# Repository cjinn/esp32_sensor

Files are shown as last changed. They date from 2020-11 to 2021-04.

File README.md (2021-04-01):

# ESP32 Sensor Module
This repository outlines an attempt to make a universal ESP32 board to conduct IoT projects with the help of sensors. As such, it is highly customisable and will most likely undergo many revisions.

The goal is to have multiple of these ESP32 sensor modules interact with each other using mesh Wi-Fi to share information with each other.

# Table of Contents
- [ESP32 Sensor Module](#esp32-sensor-module)
- [Table of Contents](#table-of-contents)
- [Hardware Versions](#hardware-versions)
  - [v0.0.3b](#v003b)
    - [v0.0.3c](#v003c)
    - [Known Hardware Issues](#known-hardware-issues)
- [Acknowledgements](#acknowledgements)

# Hardware Versions
Each hardware revision will be updated and the version as such. This version system is adopted from v0.0.4 onwards. The convection is as follows:

X.Y.ZA
- X: Major version number of the design. It is assumed there are major changes to the overall design including PCB, components, fucntionality, purpose, etc.
- Y: Minor version number of the design. Any increment on this signifies a minor design revision. Most likely an electrical characteristic change and/or component replacement.
- Z: Revision version number of the design. Any increment on this signifies a commit has been made to the design. Most likely adjustments to facilitate assembly houses, manufacturing and production.
- A: Alphabetical designation. Used to indicate even more minor adjustments like spelling mistakes and refreshing files.

## v0.0.3b
Originally a 4-layer PCB, it was redesigned to a 2-layer PCB in order to meet capstone project deadlines and it is the first iteration that was manufactured, tested and worked (well, most of it anyways). As such, it is noticebly bare-bones and has hardware design flaws. It is not recommended to go with this.

### v0.0.3c
Refreshed gerber files, schematics and BOM to be packaged such that it can be used to shop around between assembly houses. No meaningful changes since v0.0.3b.

### Known Hardware Issues
- [IMU SDA pin interferes with ESP32 boot up](https://github.com/cjinn/esp32_sensor/issues/2)
- [Crystal Oscillator missing from Hardware Design](https://github.com/cjinn/esp32_sensor/issues/1)

# Acknowledgements
Thanks to Isaac Tan for helping me design, test and realise this project from the very beginning.

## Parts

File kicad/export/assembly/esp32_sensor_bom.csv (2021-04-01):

Component | Description | Part | References | Value | Footprint | Quantity Per PCB | Datasheet | Vendor | Vendor Part Name | Part Name | Manufacturer | PROD_ID | digikeypn | PARTREV | STANDARD
1 |  | C-Device | C_ESP_1 C_PW_4 | 0.1uF | CAPC1608X90 | 2 | https://www.yageo.com/upload/media/product/productsearch/datasheet/mlcc/UPY-GPHC_X7R_6.3V-to-50V_18.pdf | DigiKey Canada | 311-1777-1-ND | CC0603JRX7R8BB104 | Yageo
2 |  | C_Small-Device | C_IMU_1 C_IMU_2 C_IMU_3 | 100nF | CAPC1608X90N | 3 | https://product.tdk.com/info/en/catalog/datasheets/mlcc_commercial_midvoltage_en.pdf | DigiKey Canada | 445-1304-1-ND | C1608X7R2A103K080AA | TDK Corporation
3 |  | C-Device | C_PW_1 C_PW_3 | 1uF | 603 | 2 | https://content.kemet.com/datasheets/KEM_C1002_X7R_SMD.pdf | DigiKey Canada | 399-7847-1-ND | C0603C105K4RACTU | Kermet
4 |  | C_Small-Device | C_PW_2 C_PW_5 | 4.7uF | C1206C475K3RACAUTO | 2 | https://api.kemet.com/component-edge/download/specsheet/C1206C475K3RACAUTO.pdf | DigiKey Canada | 399-7029-1-ND | C1206C475K3RACAUTO | Kermet
5 |  | CP-Device | CP_ESP_1 | 100uF | UCB0J101MCL1GS | 1 | https://www.nichicon.co.jp/english/products/pdfs/e-ucb.pdf | DigiKey Canada | 493-9357-1-ND | UCB0J101MCL1GS | Nichicon
6 |  | BAT20JFILM | D_PW_1 D_PW_2 D_PW_3 | BAT20JFILM | BAT20JFILM | 3 | https://www.st.com/content/ccc/resource/technical/document/datasheet/group1/81/a4/1f/0e/ca/8c/47/ba/CD00012201/files/CD00012201.pdf/jcr:content/translations/e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 | DigiKey Canada | 497-3381-1-ND | BAT20JFILM | STMicroelectronics | DIO-11623
7 |  | 4157 | J_1 J_2 | 4157 | PinSocket_1x20_P2.54mm_Vertical | 2 |  | DigiKey Canada |  |  | Adafruit Industries LLC |  | 1528-2929-ND
8 |  | Header_Pin_1 | J_CN_3 J_CN_4 J_PW_3 | Header_Pin_1 | PinHeader_1x01_P2.54mm_Vertical | 3
9 |  | Header_Pin_2 | J_PW_1 J_PW_2 | Header_Pin_2 | PinHeader_1x02_P2.54mm_Vertical | 2
10 |  | Header_Pin_4 | J_CN_1 J_CN_2 | Header_Pin_4 | PinHeader_1x04_P2.54mm_Vertical | 2
11 |  | Header_Pin_2 | J_5 | IMU_INT1 | PinHeader_1x02_P2.54mm_Vertical | 1
12 |  | Header_Pin_2 | J_4 | IMU_INT2 | PinHeader_1x02_P2.54mm_Vertical | 1
13 |  | Header_Pin_2 | J_6 | IMU_SCL | PinHeader_1x02_P2.54mm_Vertical | 1
14 |  | Header_Pin_2 | J_7 | IMU_SDA | PinHeader_1x02_P2.54mm_Vertical | 1
15 |  | Header_Pin_8 | J_3 | SPI | PinHeader_1x08_P2.54mm_Vertical | 1
16 |  | L-Device | L_PW_1 | 4.7uH | CV201210-4R7K | 1 | https://www.bourns.com/docs/Product-Datasheets/CV201210.pdf | DigiKey Canada | CV201210-4R7KCT-ND | CV201210-4R7K | Bourns Inc.
17 |  | LED-Device | LED_ESP_1 | LED | LED_0603_1608Metric | 1 | https://katalog.we-online.de/led/datasheet/150060YS75000.pdf | DigiKey Canada | 732-4981-1-ND | 150060YS75000 | Würth Elektronik
18 |  | IRLML5103TRPBF | Q_PW_1 | IRLML5103TRPBF | IRLML5103TRPBF | 1 | https://www.infineon.com/dgdl/irlml5103pbf.pdf?fileId=5546d462533600a401535668505d2617 | DigiKey Canada | IRLML5103PBFCT-ND | IRLML5103TRPBF | Infineon Technologies
19 |  | R_Small-Device | R_ESP_1 R_ESP_3 R_ESP_5 | 500 | RESC1508X55N | 3 | https://www.vishay.com/docs/28916/mcxhp.pdf | DigiKey Canada | 749-1523-1-ND | MCT0603PD4990DP500 | Vishay
20 |  | R_Small-Device | R_IMU_1 R_IMU_2 | 4.7k | RESC1608X55N | 2 | https://www.yageo.com/upload/media/product/productsearch/datasheet/rchip/PYu-RT_1-to-0.01_RoHS_L_12.pdf | DigiKey Canada | 311-4.7KDCT-ND | RT0603DRD074K7L | Yageo
21 |  | R_Small-Device | R_ESP_2 R_ESP_4 R_PW_1 | 10k | RESC1608X55N | 3 | https://www.yageo.com/upload/media/product/productsearch/datasheet/rchip/PYu-RT_1-to-0.01_RoHS_L_12.pdf | DigiKey Canada | YAG2321CT-ND | RT0603FRE0710KL | Yageo
22 |  | R_Small-Device | R_PW_2 R_PW_3 | 100k | RESC1608X55N | 2 | https://www.yageo.com/upload/media/product/productsearch/datasheet/rchip/PYu-RT_1-to-0.01_RoHS_L_12.pdf | DigiKey Canada | 311-2395-1-ND | RT0603DRE07100KL | Yageo
23 |  | R_Small-Device | R_PW_4 | 115k | RESC1608X55N | 1 | https://www.yageo.com/upload/media/product/productsearch/datasheet/rchip/PYu-RT_1-to-0.01_RoHS_L_12.pdf | DigiKey Canada | 311-2218-1-ND | RT0402DRE07115KL | Yageo
24 |  | PTS647SK38SMTR2LFS | SW_ESP_1 SW_ESP_2 | PTS647SK38SMTR2LFS | PTS647SK38SMTR2LFS | 2 | https://www.ckswitches.com/media/2567/pts647.pdf | DigiKey Canada | PTS647SK38SMTR2LFSCT-ND | PTS 647 SK38 SMTR2 LFS | C&K
25 |  | ESP32-WROOM-32D-RF_Module | U_ESP_1 | ESP32-WROOM-32D | ESP32-WROOM-32 | 1 | https://www.espressif.com/sites/default/files/documentation/esp32-wroom-32d_esp32-wroom-32u_datasheet_en.pdf | DigiKey Canada | 1965-ESP32-WROOM-32D(4MB)CT-ND | USB4110-GF-A | Espressif Systems
26 |  | LSM6DSMTR | U_IMU_1 | LSM6DSMTR | LSM6DSMTR | 1 | https://www.st.com/content/ccc/resource/technical/document/datasheet/76/27/cf/88/c5/03/42/6b/DM00218116.pdf/files/DM00218116.pdf/jcr:content/translations/en.D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 | DigiKey Canada | 497-16696-1-ND | LSM6DSMTR | STMicroelectronics
27 |  | MAX25276ATCA_VY+ | U_PW_1 | MAX25276ATCA_VY+ | MAX25276ATCAVY | 1 | https://datasheets.maximintegrated.com/en/ds/MAX20075-MAX25276.pdf | DigiKey Canada | 175-MAX25276ATCA/VY+-ND | MAX25276ATCA_VY+ | Maxim Integrated
28 |  | USB4110-GF-A | U_CN_1 | USB4110-GF-A | USB4110-GF-A | 1 | https://gct.co/files/drawings/usb4110.pdf | DigiKey Canada | 2073-USB4110-GF-A-1-ND | PTS647SK38SMTR2LFS | GCT |  |  | A | Manufacturer Recommendations
Component Groups: | 28
Component Count: | 47
Fitted Components: | 47
Number of PCBs: | 1
Total components: | 47
Schematic Version: | v0.0.3
Schematic Date: | 31/3/2021
PCB Variant: | udefault
BoM Date: | 03/31/21 16:14:19
Schematic Source: | esp32_sensor.sch
KiCad Version: | Eeschema (5.1.9)-1

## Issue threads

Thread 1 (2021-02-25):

Crystal Oscillator missing from Hardware Design

cjinn, 2021-02-25:
## Summary
As noted in the[ Hardware Design Guidelines](https://www.espressif.com/sites/default/files/documentation/esp32_hardware_design_guidelines_en.pdf) on page 6 for the External Clock Source, the ESP32 requires a 40 MHz crystal oscillator in order to run Wi-Fi/Bluetooth firmware. This is an oversight on the hardware design, causing any firmware for Wi-Fi/Bluetooth to fail for v0.0.3b.

## Proposed Solution
In the next hardware iteration, include a crystal oscillator into the design.

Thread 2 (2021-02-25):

IMU SDA pin interferes with ESP32 boot up

cjinn, 2021-02-25:
## Summary
In the current hardware design, the ESP32 will not boot up properly if it is connected to the IMU on start-up, specifically the IMU SDA pin with GPIO12 (MTDI) or Pin14 for the ESP32. The [ESP32 Boot Mode ](https://github.com/espressif/esptool/wiki/ESP32-Boot-Mode-Selection), when driven high, will have a flash voltage of 1.8V which interferes with the 3.3V SPI Flash as outlined in the [ESP32 datasheet](https://www.espressif.com/sites/default/files/documentation/esp32-wroom-32d_esp32-wroom-32u_datasheet_en.pdf).

The current workaround is to not connect the IMU to the ESP32 till after power up.

## Proposed Solution
Revise GPIO layout of the ESP32 to connect to IMU.

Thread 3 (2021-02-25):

IMU Self-Reset with FTDI

cjinn, 2021-02-25:
The ESP32 should interface with the FTDI hardware pins such that it can auto-reset itself accordingly when being programmed.

See [this thread](https://forum.micropython.org/viewtopic.php?f=18&t=4966) for an example.

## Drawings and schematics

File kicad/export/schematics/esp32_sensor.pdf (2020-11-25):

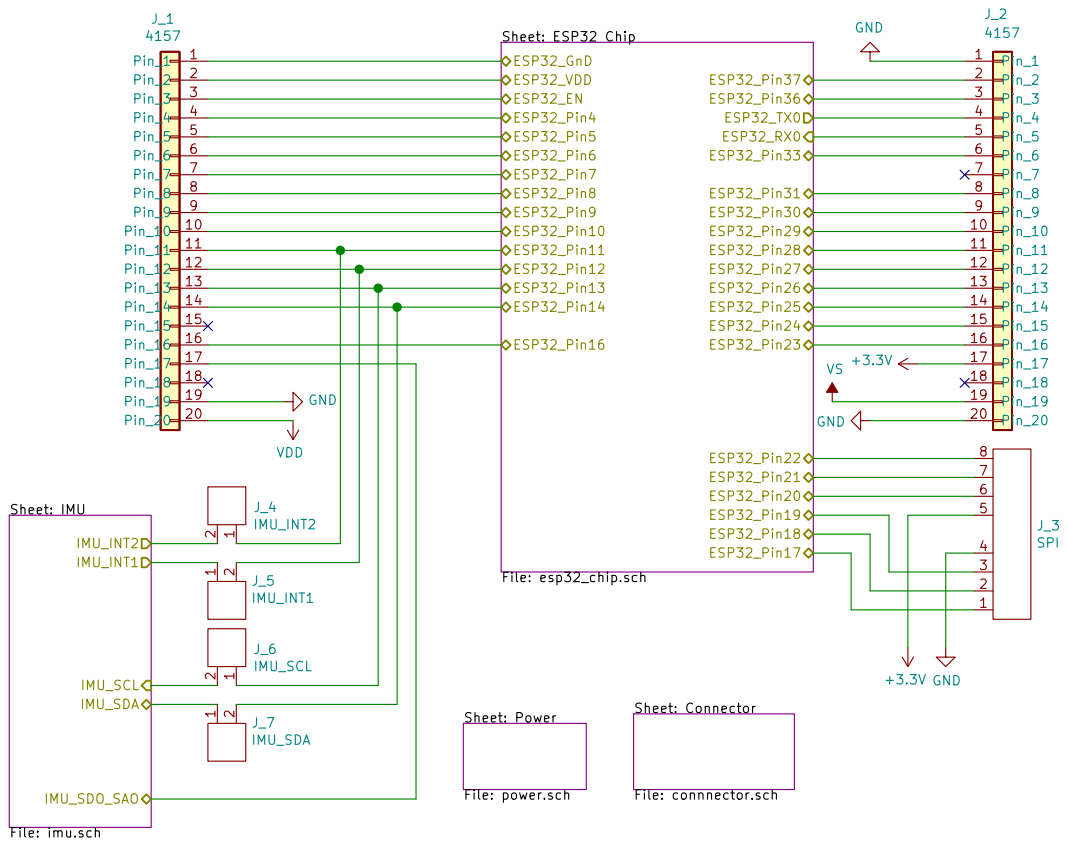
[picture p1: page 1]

Component Identifier: Sheet: IMU

Sheet: Connector File: connnector.sch

File: esp32_sensor.sch Sheet: / Created by Choong Jin Ng | jin3838@gmail.com

Id: 1/5 Title: ESP32 Sensor Module

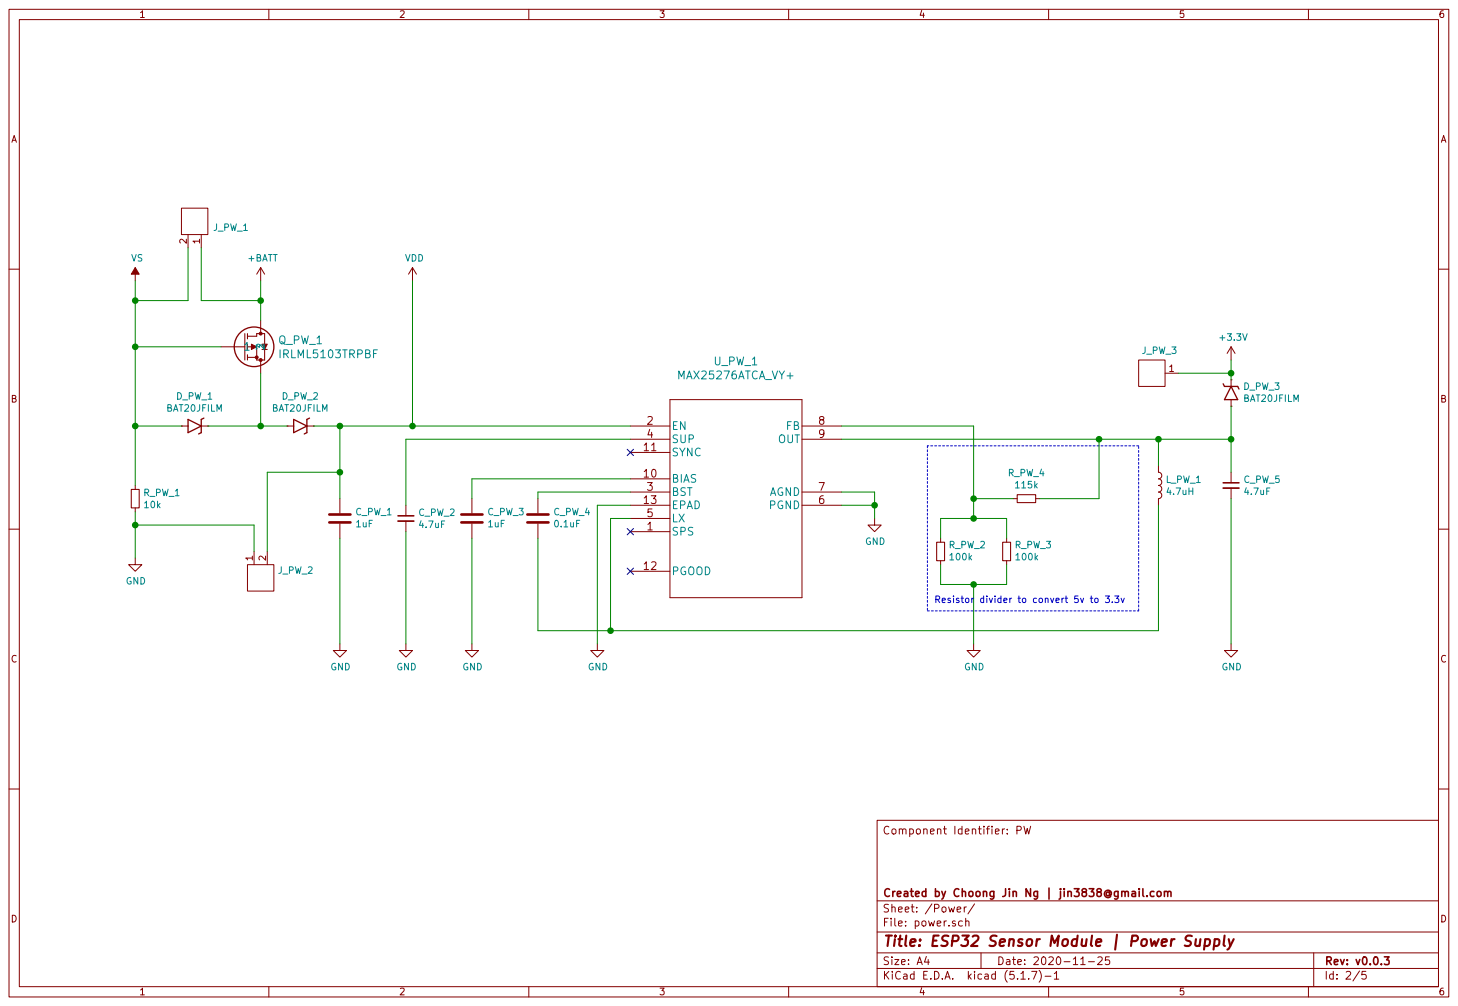
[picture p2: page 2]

File: power.sch Sheet: /Power/ Created by Choong Jin Ng | jin3838@gmail.com

Id: 2/5 Title: ESP32 Sensor Module | Power Supply

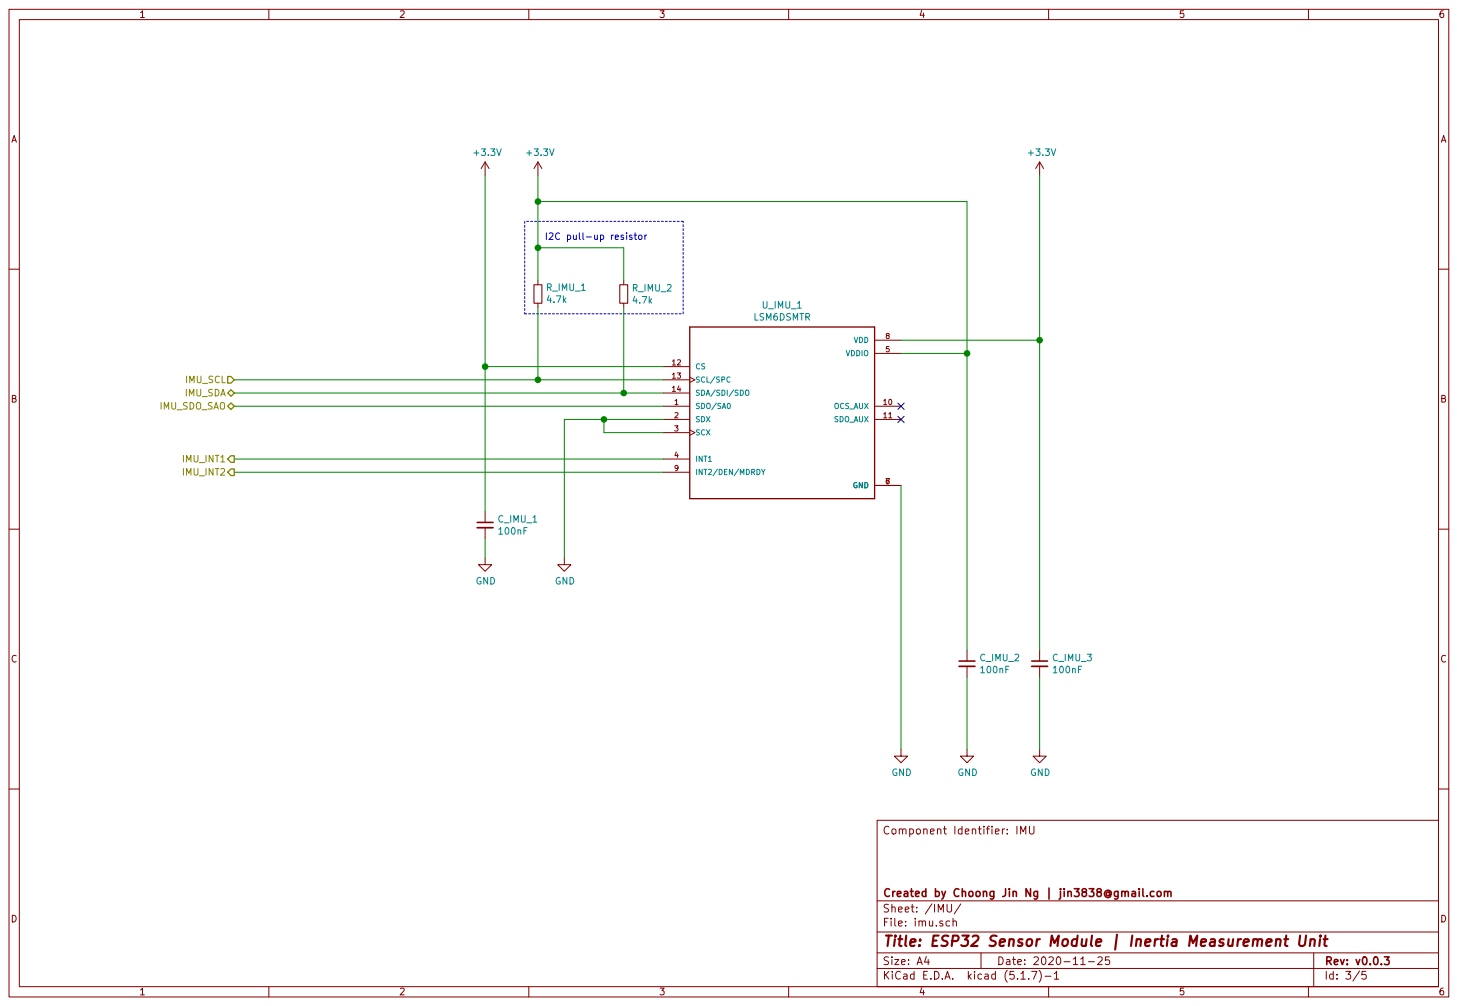
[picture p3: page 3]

Id: 3/5 Title: ESP32 Sensor Module | Inertia Measurement Unit File: imu.sch Sheet: /IMU/ Created by Choong Jin Ng | jin3838@gmail.com

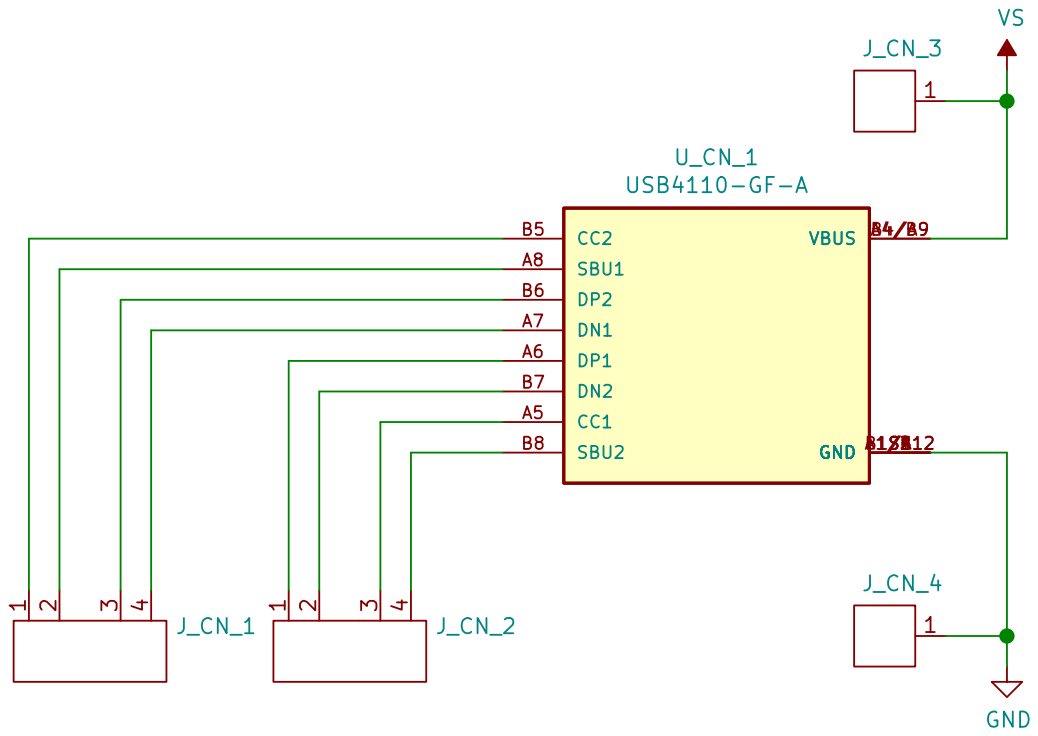
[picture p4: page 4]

Id: 4/5 Title: ESP32 Sensor Module | Connector File: connnector.sch Sheet: /Connector/ Created by Choong Jin Ng | jin3838@gmail.com

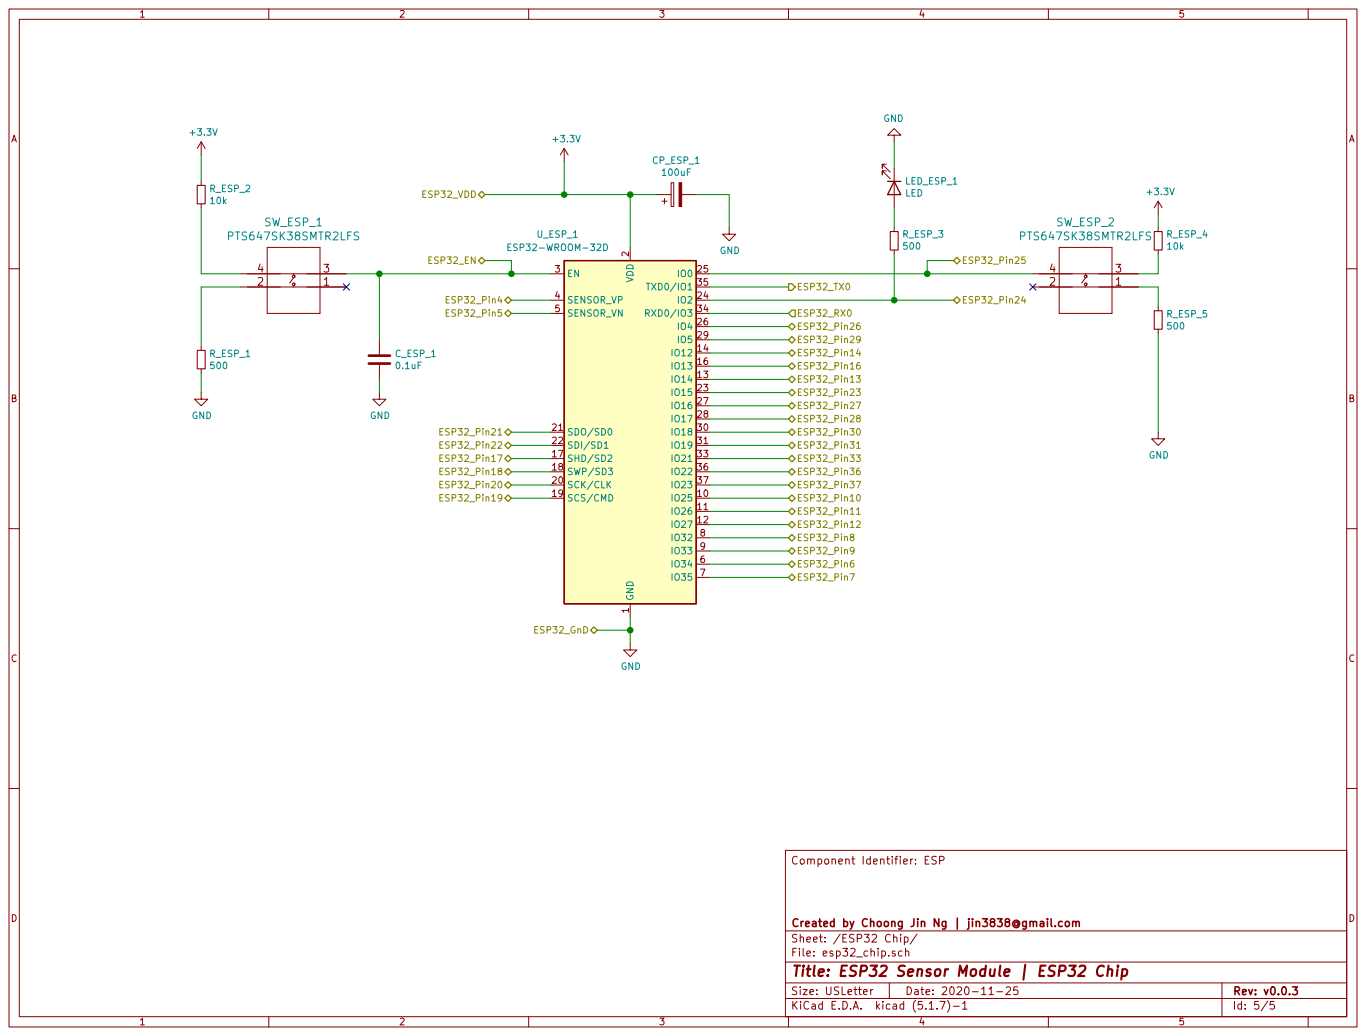
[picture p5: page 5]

2 SCK/CLK 20 SDO/SD0 21 SDI/SD1 22

Created by Choong Jin Ng | jin3838@gmail.com
Sheet: /ESP32 Chip/
File: esp32_chip.sch
Id: 5/5 Title: ESP32 Sensor Module | ESP32 Chip

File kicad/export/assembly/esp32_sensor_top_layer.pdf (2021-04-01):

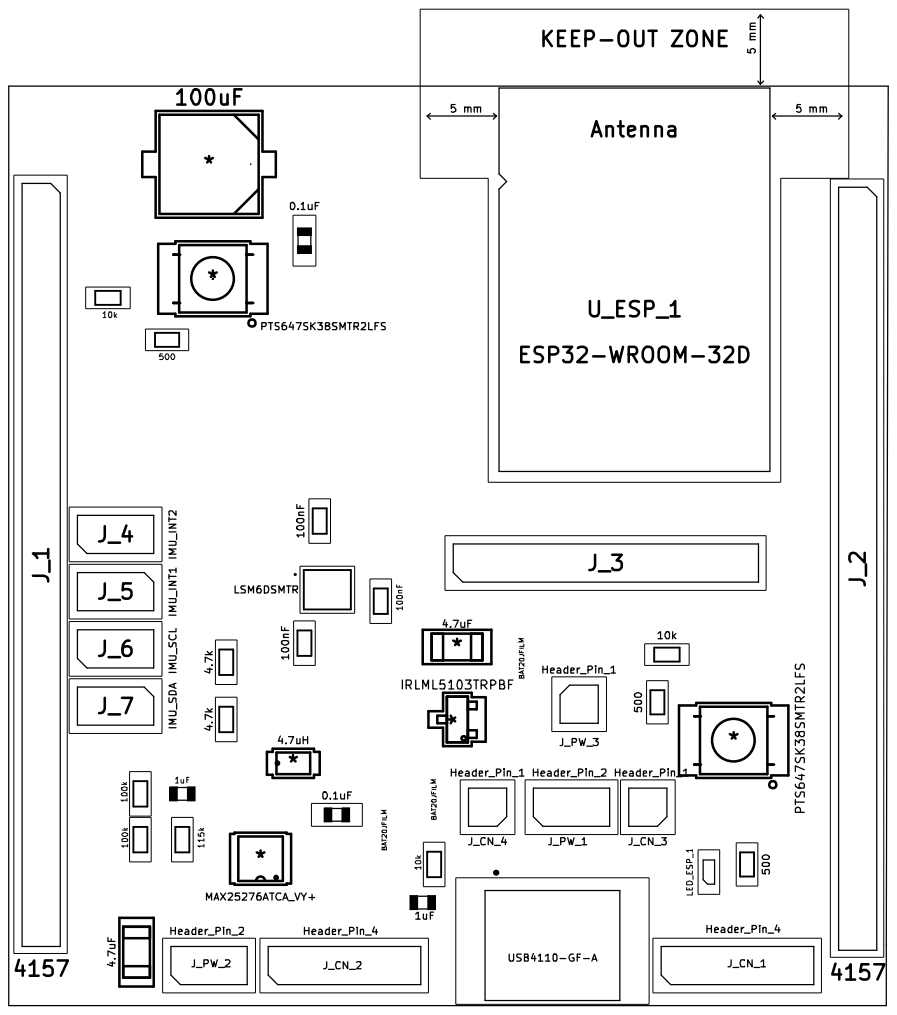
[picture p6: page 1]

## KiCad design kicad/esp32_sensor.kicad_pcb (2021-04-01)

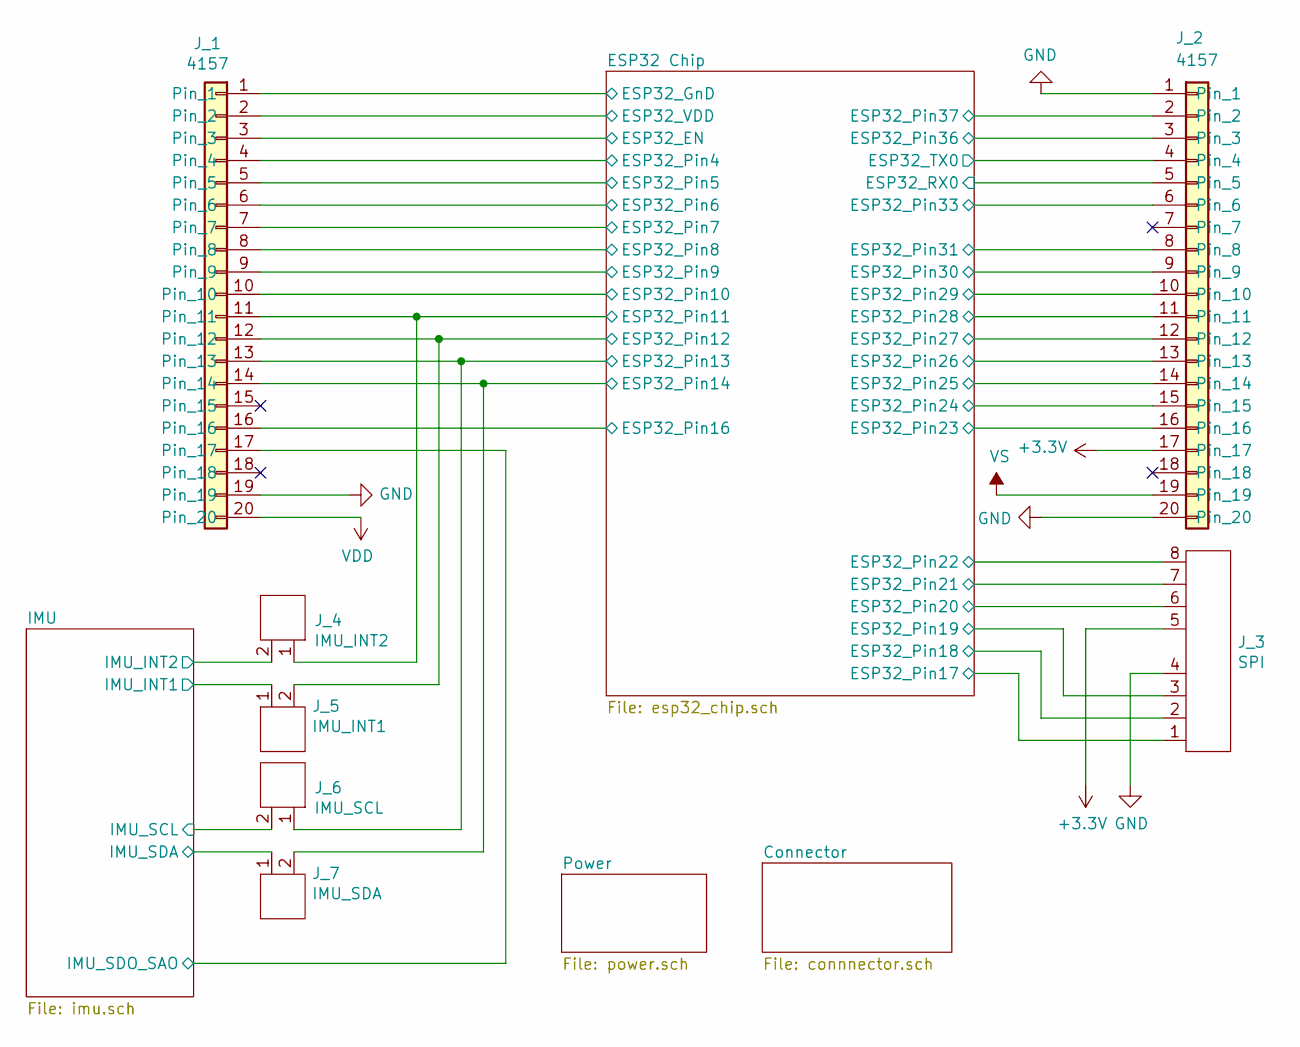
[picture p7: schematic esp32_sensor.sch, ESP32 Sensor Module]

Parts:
J_1, J_2: 4157; PinSocket_1x20_P2.54mm_Vertical; digikeypn 1528-2929-ND
J_3: SPI; PinHeader_1x08_P2.54mm_Vertical
J_4: IMU_INT2; PinHeader_1x02_P2.54mm_Vertical
J_5: IMU_INT1; PinHeader_1x02_P2.54mm_Vertical
J_6: IMU_SCL; PinHeader_1x02_P2.54mm_Vertical
J_7: IMU_SDA; PinHeader_1x02_P2.54mm_Vertical

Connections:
+3V3: J_1.2, J_2.17, J_3.5; also elsewhere on the board
/ESP32 Chip/ESP32_EN: J_1.3; also elsewhere on the board
/ESP32 Chip/ESP32_Pin4: J_1.4; also elsewhere on the board
/ESP32 Chip/ESP32_Pin5: J_1.5; also elsewhere on the board
/ESP32 Chip/ESP32_Pin6: J_1.6; also elsewhere on the board
/ESP32 Chip/ESP32_Pin7: J_1.7; also elsewhere on the board
/ESP32 Chip/ESP32_Pin8: J_1.8; also elsewhere on the board
/ESP32 Chip/ESP32_Pin9: J_1.9; also elsewhere on the board
/ESP32 Chip/ESP32_Pin10: J_1.10; also elsewhere on the board
/ESP32 Chip/ESP32_Pin11: J_1.11, J_4.1; also elsewhere on the board
/ESP32 Chip/ESP32_Pin12: J_1.12, J_5.2; also elsewhere on the board
/ESP32 Chip/ESP32_Pin13: J_1.13, J_6.1; also elsewhere on the board
/ESP32 Chip/ESP32_Pin14: J_1.14, J_7.2; also elsewhere on the board
/ESP32 Chip/ESP32_Pin16: J_1.16; also elsewhere on the board
/ESP32 Chip/ESP32_Pin17: J_3.1; also elsewhere on the board
/ESP32 Chip/ESP32_Pin18: J_3.2; also elsewhere on the board
/ESP32 Chip/ESP32_Pin19: J_3.3; also elsewhere on the board
/ESP32 Chip/ESP32_Pin20: J_3.6; also elsewhere on the board
/ESP32 Chip/ESP32_Pin21: J_3.7; also elsewhere on the board
/ESP32 Chip/ESP32_Pin22: J_3.8; also elsewhere on the board
/ESP32 Chip/ESP32_Pin23: J_2.16; also elsewhere on the board
/ESP32 Chip/ESP32_Pin24: J_2.15; also elsewhere on the board
/ESP32 Chip/ESP32_Pin25: J_2.14; also elsewhere on the board
/ESP32 Chip/ESP32_Pin26: J_2.13; also elsewhere on the board
/ESP32 Chip/ESP32_Pin27: J_2.12; also elsewhere on the board
/ESP32 Chip/ESP32_Pin28: J_2.11; also elsewhere on the board
/ESP32 Chip/ESP32_Pin29: J_2.10; also elsewhere on the board
/ESP32 Chip/ESP32_Pin30: J_2.9; also elsewhere on the board
/ESP32 Chip/ESP32_Pin31: J_2.8; also elsewhere on the board
/ESP32 Chip/ESP32_Pin33: J_2.6; also elsewhere on the board
/ESP32 Chip/ESP32_Pin36: J_2.3; also elsewhere on the board
/ESP32 Chip/ESP32_Pin37: J_2.2; also elsewhere on the board
/ESP32 Chip/ESP32_RX0: J_2.5; also elsewhere on the board
/ESP32 Chip/ESP32_TX0: J_2.4; also elsewhere on the board
/IMU/IMU_INT1: J_5.1; also elsewhere on the board
/IMU/IMU_INT2: J_4.2; also elsewhere on the board
/IMU/IMU_SCL: J_6.2; also elsewhere on the board
/IMU/IMU_SDA: J_7.1; also elsewhere on the board
/IMU/IMU_SDO_SAO: J_1.17; also elsewhere on the board
GND: J_1.1, J_1.19, J_2.1, J_2.20, J_3.4; also elsewhere on the board
VDD: J_1.20; also elsewhere on the board
VS: J_2.19; also elsewhere on the board

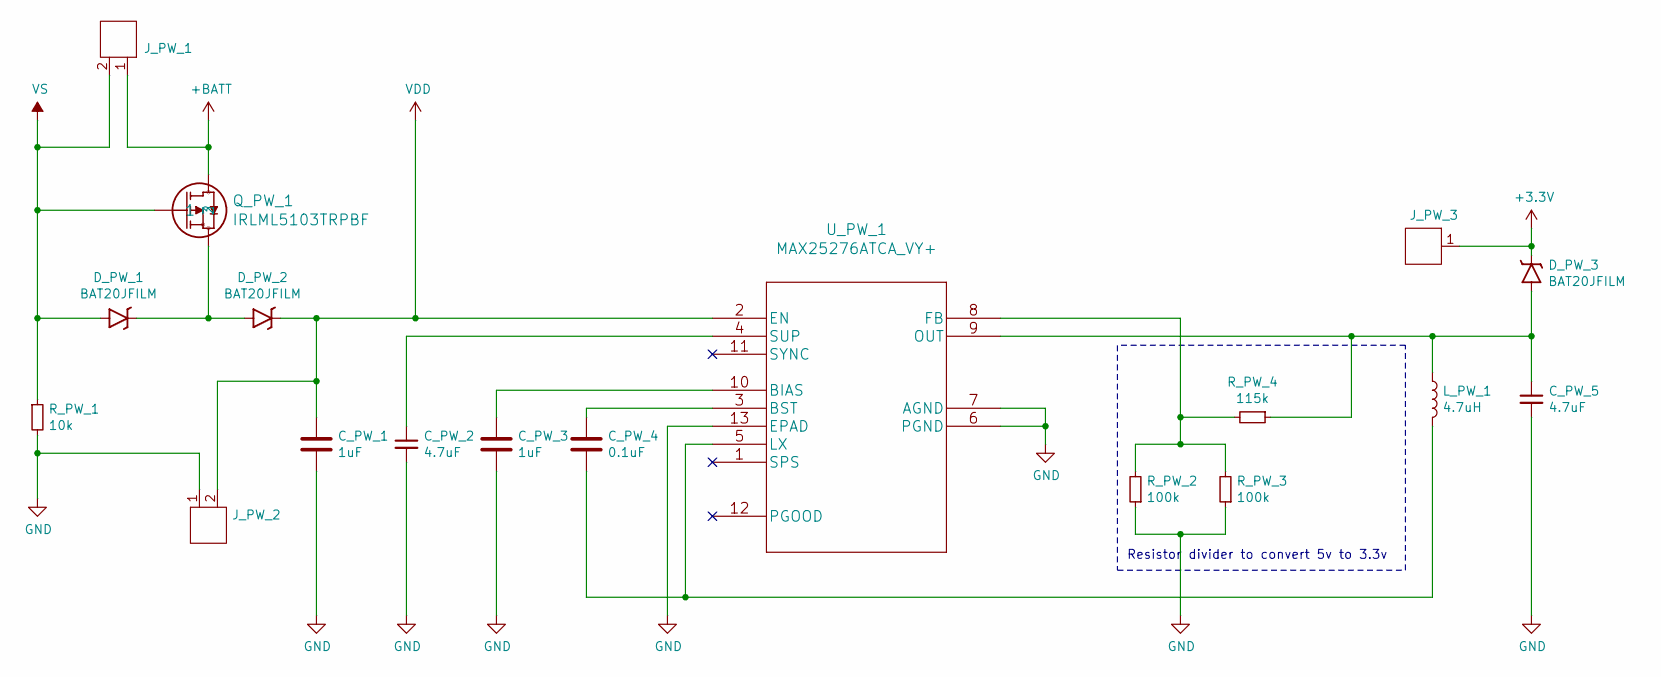
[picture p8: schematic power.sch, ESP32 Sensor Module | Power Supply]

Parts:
C_PW_1, C_PW_3: 1uF; 0603; Part Name C0603C105K4RACTU
C_PW_2, C_PW_5: 4.7uF; C1206C475K3RACAUTO; Part Name C1206C475K3RACAUTO
C_PW_4: 0.1uF; CAPC1608X90; Part Name CC0603JRX7R8BB104
D_PW_1, D_PW_2, D_PW_3: BAT20JFILM; Part Name BAT20JFILM
J_PW_1, J_PW_2: Header_Pin_2; PinHeader_1x02_P2.54mm_Vertical
J_PW_3: Header_Pin_1; PinHeader_1x01_P2.54mm_Vertical
L_PW_1: 4.7uH; CV201210-4R7K; Part Name CV201210-4R7K
Q_PW_1: IRLML5103TRPBF; Part Name IRLML5103TRPBF
R_PW_1: 10k; RESC1608X55N; Part Name RT0603FRE0710KL
R_PW_2, R_PW_3: 100k; RESC1608X55N; Part Name RT0603DRE07100KL
R_PW_4: 115k; RESC1608X55N; Part Name RT0402DRE07115KL
U_PW_1: MAX25276ATCA_VY+; MAX25276ATCAVY; Part Name MAX25276ATCA_VY+

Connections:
+3V3: D_PW_3.C, J_PW_3.1; also elsewhere on the board
+BATT: J_PW_1.1, Q_PW_1.2
GND: C_PW_1.1, C_PW_2.2, C_PW_3.1, C_PW_5.2, J_PW_2.1, R_PW_1.2, R_PW_2.1, R_PW_3.1, U_PW_1.6 (PGND), U_PW_1.7 (AGND), U_PW_1.13 (EPAD); also elsewhere on the board
unnamed: C_PW_2.1, U_PW_1.4 (SUP)
unnamed: C_PW_3.2, U_PW_1.10 (BIAS)
unnamed: C_PW_4.1, L_PW_1.2, U_PW_1.5 (LX)
unnamed: C_PW_4.2, U_PW_1.3 (BST)
unnamed: C_PW_5.1, D_PW_3.A, L_PW_1.1, R_PW_4.1, U_PW_1.9 (OUT)
unnamed: D_PW_1.C, D_PW_2.A, Q_PW_1.3
unnamed: R_PW_2.2, R_PW_3.2, R_PW_4.2, U_PW_1.8 (FB)
VDD: C_PW_1.2, D_PW_2.C, J_PW_2.2, U_PW_1.2 (EN); also elsewhere on the board
VS: D_PW_1.A, J_PW_1.2, Q_PW_1.1, R_PW_1.1; also elsewhere on the board

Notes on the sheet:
Resistor divider to convert 5v to 3.3v

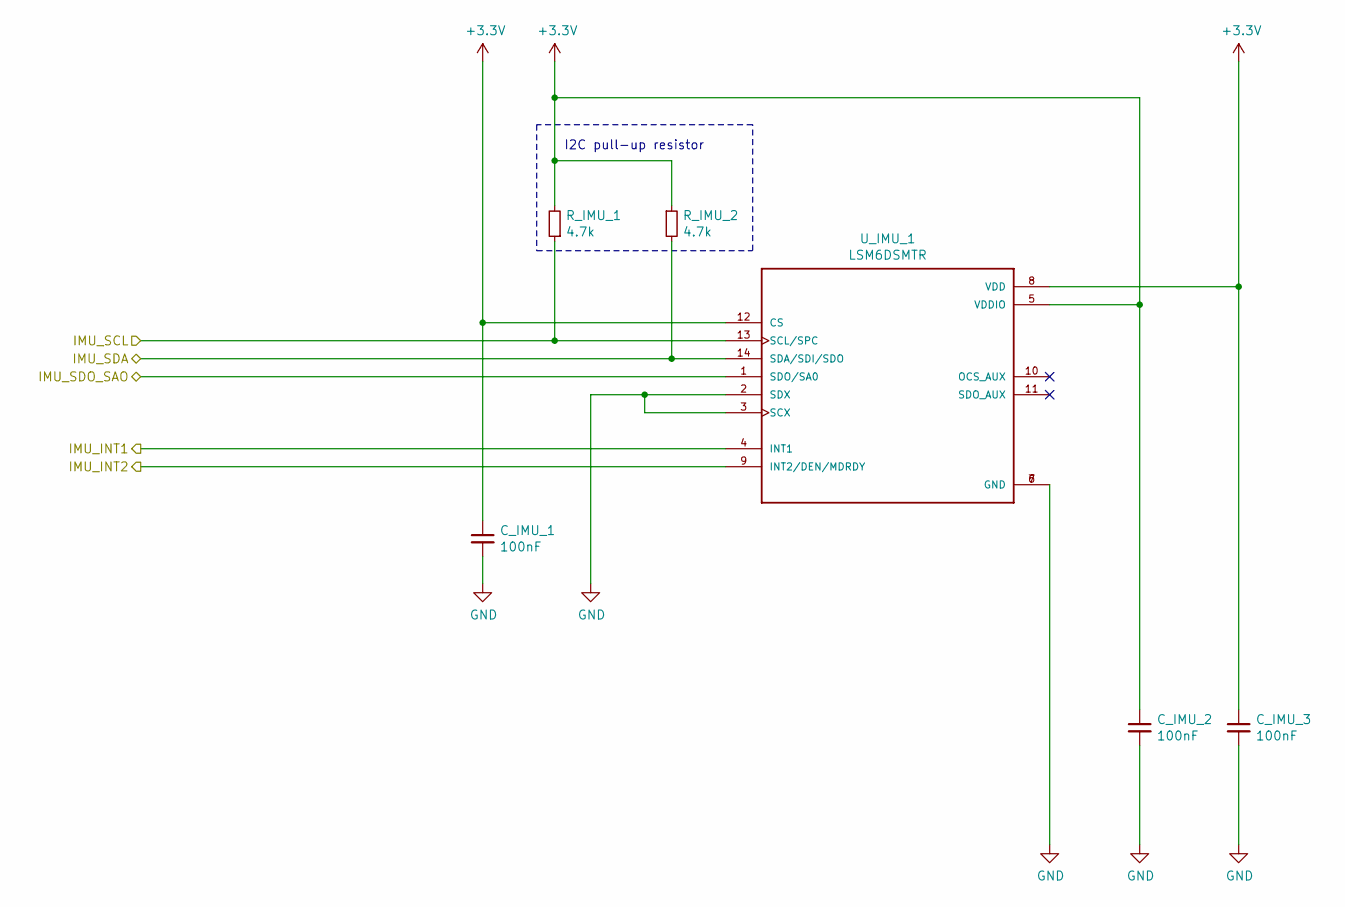
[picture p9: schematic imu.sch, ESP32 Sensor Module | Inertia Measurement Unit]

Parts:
C_IMU_1, C_IMU_2, C_IMU_3: 100nF; CAPC1608X90N; Part Name C1608X7R2A103K080AA
R_IMU_1, R_IMU_2: 4.7k; RESC1608X55N; Part Name RT0603DRD074K7L
U_IMU_1: LSM6DSMTR; Part Name LSM6DSMTR

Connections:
+3V3: C_IMU_1.1, C_IMU_2.1, C_IMU_3.1, R_IMU_1.2, R_IMU_2.1, U_IMU_1.5 (VDDIO), U_IMU_1.8 (VDD), U_IMU_1.12 (CS); also elsewhere on the board
/IMU/IMU_INT1: U_IMU_1.4 (INT1); also elsewhere on the board
/IMU/IMU_INT2: U_IMU_1.9 (INT2/DEN/MDRDY); also elsewhere on the board
/IMU/IMU_SCL: R_IMU_1.1, U_IMU_1.13 (SCL/SPC); also elsewhere on the board
/IMU/IMU_SDA: R_IMU_2.2, U_IMU_1.14 (SDA/SDI/SDO); also elsewhere on the board
/IMU/IMU_SDO_SAO: U_IMU_1.1 (SDO/SA0); also elsewhere on the board
GND: C_IMU_1.2, C_IMU_2.2, C_IMU_3.2, U_IMU_1.2 (SDX), U_IMU_1.3 (SCX), U_IMU_1.6 (GND), U_IMU_1.7 (GND); also elsewhere on the board

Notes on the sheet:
I2C pull-up resistor

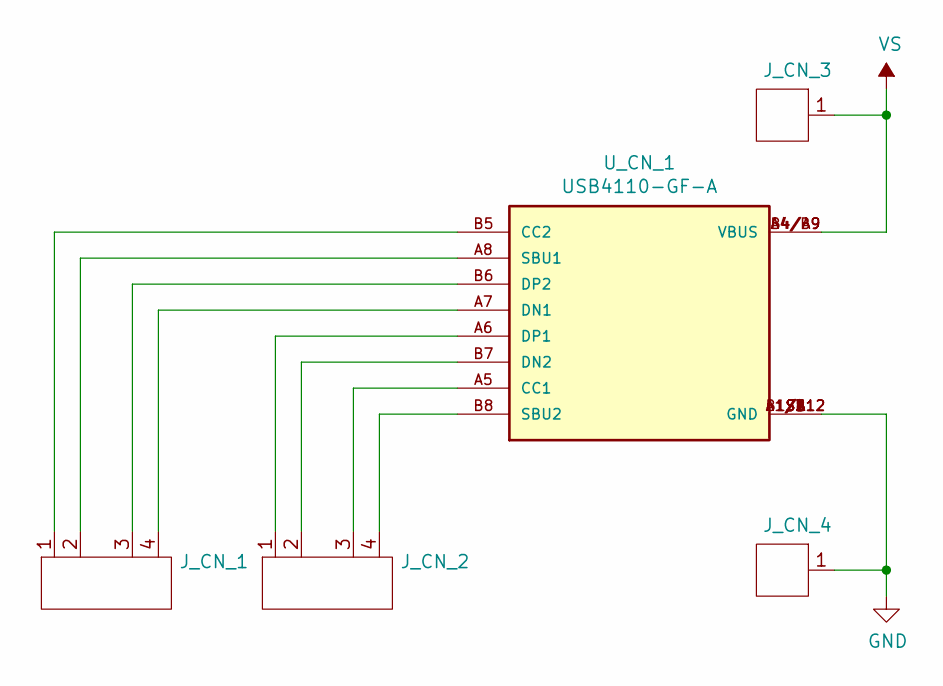
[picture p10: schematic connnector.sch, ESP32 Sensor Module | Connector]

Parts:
J_CN_1, J_CN_2: Header_Pin_4; PinHeader_1x04_P2.54mm_Vertical
J_CN_3, J_CN_4: Header_Pin_1; PinHeader_1x01_P2.54mm_Vertical
U_CN_1: USB4110-GF-A; PARTREV A

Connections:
GND: J_CN_4.1, U_CN_1.A1/B12 (GND), U_CN_1.B1/A12 (GND), U_CN_1.S1 (GND), U_CN_1.S2 (GND), U_CN_1.S3 (GND), U_CN_1.S4 (GND); also elsewhere on the board
unnamed: J_CN_1.1, U_CN_1.B5 (CC2)
unnamed: J_CN_1.2, U_CN_1.A8 (SBU1)
unnamed: J_CN_1.3, U_CN_1.B6 (DP2)
unnamed: J_CN_1.4, U_CN_1.A7 (DN1)
unnamed: J_CN_2.1, U_CN_1.A6 (DP1)
unnamed: J_CN_2.2, U_CN_1.B7 (DN2)
unnamed: J_CN_2.3, U_CN_1.A5 (CC1)
unnamed: J_CN_2.4, U_CN_1.B8 (SBU2)
VS: J_CN_3.1, U_CN_1.A4/B9 (VBUS), U_CN_1.B4/A9 (VBUS); also elsewhere on the board

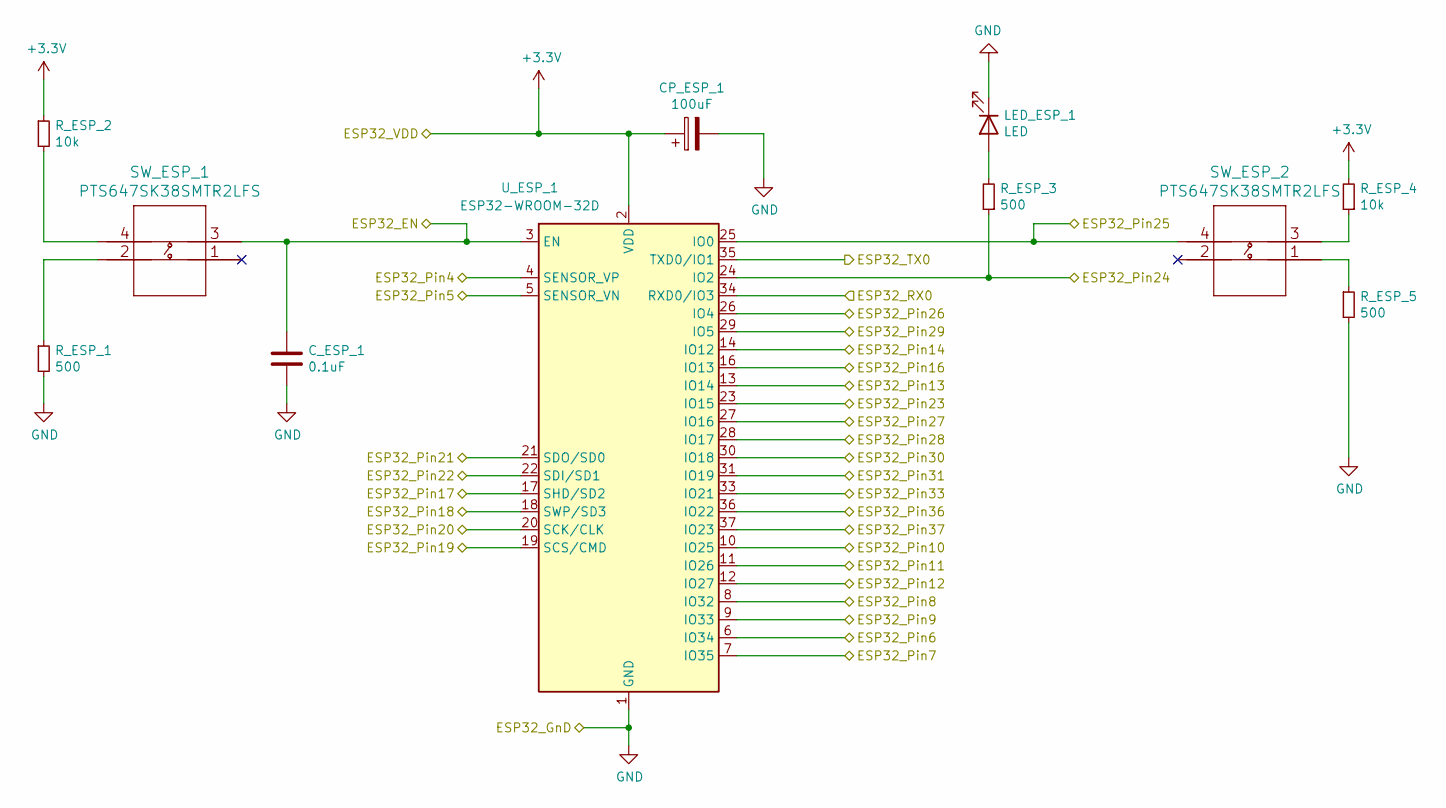
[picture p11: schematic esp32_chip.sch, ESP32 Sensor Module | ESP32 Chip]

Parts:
CP_ESP_1: 100uF; UCB0J101MCL1GS; Part Name UCB0J101MCL1GS
C_ESP_1: 0.1uF; CAPC1608X90; Part Name CC0603JRX7R8BB104
LED_ESP_1: LED; LED_0603_1608Metric; Part Name 150060YS75000
R_ESP_1, R_ESP_3, R_ESP_5: 500; RESC1508X55N; Part Name MCT0603PD4990DP500
R_ESP_2, R_ESP_4: 10k; RESC1608X55N; Part Name RT0603FRE0710KL
SW_ESP_1, SW_ESP_2: PTS647SK38SMTR2LFS; Part Name PTS 647 SK38 SMTR2 LFS
U_ESP_1: ESP32-WROOM-32D; ESP32-WROOM-32; Part Name USB4110-GF-A

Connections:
+3V3: CP_ESP_1.1, R_ESP_2.1, R_ESP_4.2, U_ESP_1.2 (VDD); also elsewhere on the board
/ESP32 Chip/ESP32_EN: C_ESP_1.1, SW_ESP_1.3, U_ESP_1.3 (EN); also elsewhere on the board
/ESP32 Chip/ESP32_Pin4: U_ESP_1.4 (SENSOR_VP); also elsewhere on the board
/ESP32 Chip/ESP32_Pin5: U_ESP_1.5 (SENSOR_VN); also elsewhere on the board
/ESP32 Chip/ESP32_Pin6: U_ESP_1.6 (IO34); also elsewhere on the board
/ESP32 Chip/ESP32_Pin7: U_ESP_1.7 (IO35); also elsewhere on the board
/ESP32 Chip/ESP32_Pin8: U_ESP_1.8 (IO32); also elsewhere on the board
/ESP32 Chip/ESP32_Pin9: U_ESP_1.9 (IO33); also elsewhere on the board
/ESP32 Chip/ESP32_Pin10: U_ESP_1.10 (IO25); also elsewhere on the board
/ESP32 Chip/ESP32_Pin11: U_ESP_1.11 (IO26); also elsewhere on the board
/ESP32 Chip/ESP32_Pin12: U_ESP_1.12 (IO27); also elsewhere on the board
/ESP32 Chip/ESP32_Pin13: U_ESP_1.13 (IO14); also elsewhere on the board
/ESP32 Chip/ESP32_Pin14: U_ESP_1.14 (IO12); also elsewhere on the board
/ESP32 Chip/ESP32_Pin16: U_ESP_1.16 (IO13); also elsewhere on the board
/ESP32 Chip/ESP32_Pin17: U_ESP_1.17 (SHD/SD2); also elsewhere on the board
/ESP32 Chip/ESP32_Pin18: U_ESP_1.18 (SWP/SD3); also elsewhere on the board
/ESP32 Chip/ESP32_Pin19: U_ESP_1.19 (SCS/CMD); also elsewhere on the board
/ESP32 Chip/ESP32_Pin20: U_ESP_1.20 (SCK/CLK); also elsewhere on the board
/ESP32 Chip/ESP32_Pin21: U_ESP_1.21 (SDO/SD0); also elsewhere on the board
/ESP32 Chip/ESP32_Pin22: U_ESP_1.22 (SDI/SD1); also elsewhere on the board
/ESP32 Chip/ESP32_Pin23: U_ESP_1.23 (IO15); also elsewhere on the board
/ESP32 Chip/ESP32_Pin24: R_ESP_3.1, U_ESP_1.24 (IO2); also elsewhere on the board
/ESP32 Chip/ESP32_Pin25: SW_ESP_2.4, U_ESP_1.25 (IO0); also elsewhere on the board
/ESP32 Chip/ESP32_Pin26: U_ESP_1.26 (IO4); also elsewhere on the board
/ESP32 Chip/ESP32_Pin27: U_ESP_1.27 (IO16); also elsewhere on the board
/ESP32 Chip/ESP32_Pin28: U_ESP_1.28 (IO17); also elsewhere on the board
/ESP32 Chip/ESP32_Pin29: U_ESP_1.29 (IO5); also elsewhere on the board
/ESP32 Chip/ESP32_Pin30: U_ESP_1.30 (IO18); also elsewhere on the board
/ESP32 Chip/ESP32_Pin31: U_ESP_1.31 (IO19); also elsewhere on the board
/ESP32 Chip/ESP32_Pin33: U_ESP_1.33 (IO21); also elsewhere on the board
/ESP32 Chip/ESP32_Pin36: U_ESP_1.36 (IO22); also elsewhere on the board
/ESP32 Chip/ESP32_Pin37: U_ESP_1.37 (IO23); also elsewhere on the board
/ESP32 Chip/ESP32_RX0: U_ESP_1.34 (RXD0/IO3); also elsewhere on the board
/ESP32 Chip/ESP32_TX0: U_ESP_1.35 (TXD0/IO1); also elsewhere on the board
GND: CP_ESP_1.2, C_ESP_1.2, LED_ESP_1.1 (K), R_ESP_1.2, R_ESP_5.2, U_ESP_1.1 (GND), U_ESP_1.15 (GND), U_ESP_1.38 (GND), U_ESP_1.39 (GND); also elsewhere on the board
unnamed: LED_ESP_1.2 (A), R_ESP_3.2
unnamed: R_ESP_1.1, SW_ESP_1.2
unnamed: R_ESP_2.2, SW_ESP_1.4
unnamed: R_ESP_4.1, SW_ESP_2.3
unnamed: R_ESP_5.1, SW_ESP_2.1

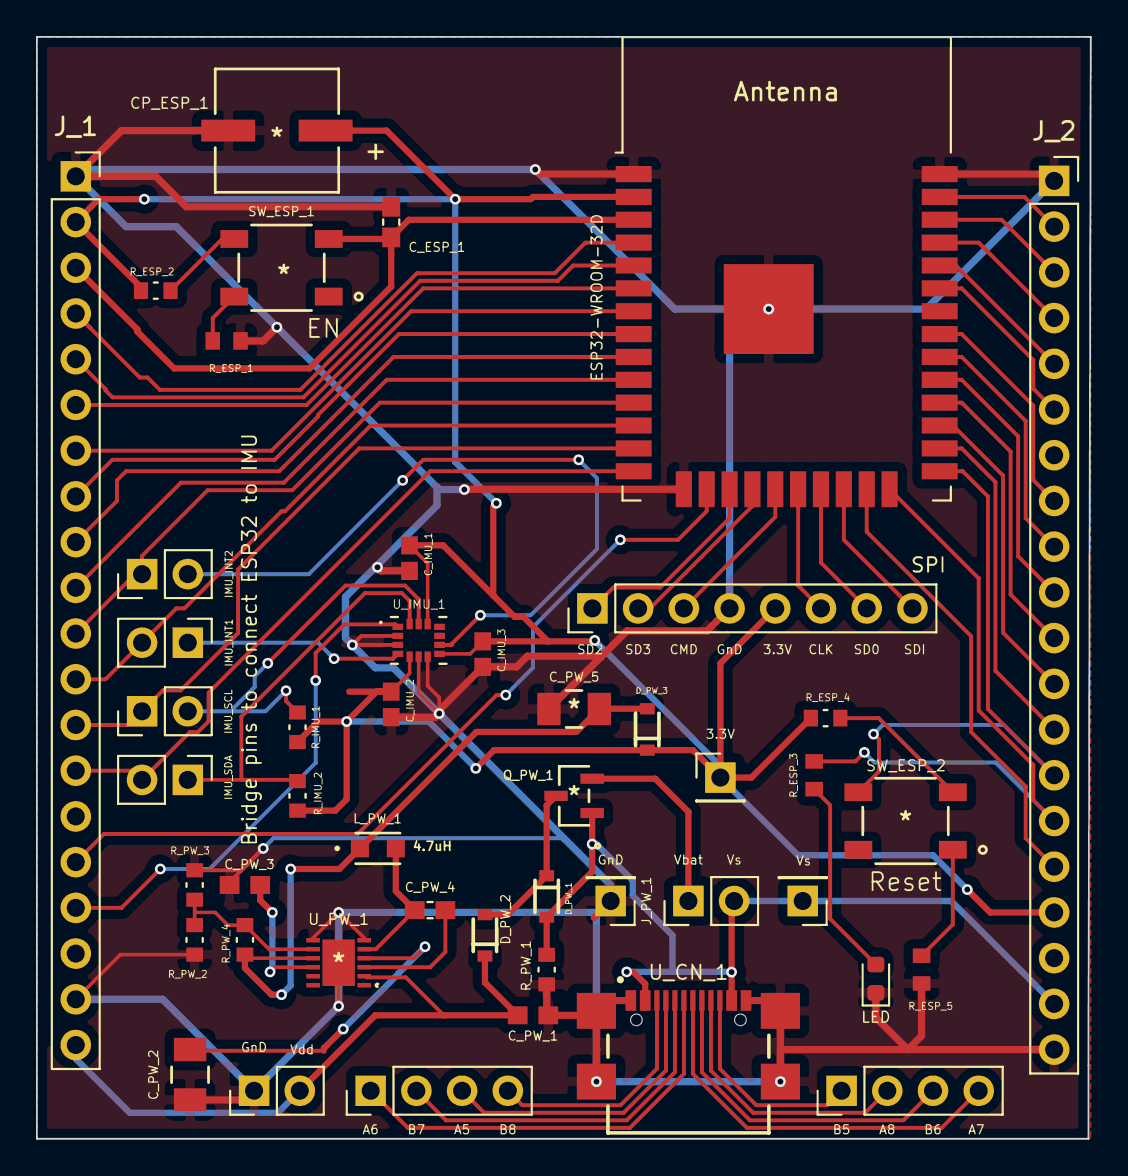
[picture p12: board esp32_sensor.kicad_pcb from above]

Board: 2 copper layers, 58.5 x 61.2 mm, 47 parts (0 on the bottom side), 63 nets.

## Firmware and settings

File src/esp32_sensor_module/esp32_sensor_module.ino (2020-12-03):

/**
   ESP32 Sensor Module

   ESP32 Datasheet: https://www.espressif.com/sites/default/files/documentation/esp32-wroom-32_datasheet_en.pdf
   IMU Library Reference: https://github.com/arduino-libraries/Arduino_LSM6DS3/blob/master/src/LSM6DS3.cpp
   IMU Datasheet: https://www.st.com/content/ccc/resource/technical/document/datasheet/76/27/cf/88/c5/03/42/6b/DM00218116.pdf/files/DM00218116.pdf/jcr:content/translations/en.DM002181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
   ESP-NOW and WiFi:
    https://randomnerdtutorials.com/esp-now-two-way-communication-esp32/
    https://randomnerdtutorials.com/esp-now-esp32-arduino-ide/
    https://gist.github.com/futechiot/ee0223dd269cbe7d8605ce97d120d7d2

*/


/**
   Metadata
*/
#define SW_VERSION "0.0.1"
#define HW_VERSION "0.0.3b"

/**
   Libraries
*/
#include "WiFi.h"
#include "Wire.h" // ESP32 Wire.h
#include <esp_now.h>

/**
   ESP32 Pins
*/
#define IMU_INT2      26 // Pin 11
#define IMU_INT1      27 // Pin 12  
#define IMU_SCL       14 // Pin 13
#define IMU_SDA       12 // Pin 14
//#define IMU_SD0       // Not implemented


/**
   LSM Registers
*/
#define LSM6DSM_ADDRESS             0x6B // SD0 should not be connected

#define LSM6DSM_WHO_AM_I_REG        0X0F
#define WHO_AM_I_REG_VALUE          0x6A

#define LSM6DSM_CTRL1_XL            0X10
#define LSM6DSM_CTRL2_G             0X11
#define LSM5DSM_CTRL3_C             0X12

#define LSM6DSM_STATUS_REG          0X1E

#define LSM6DSM_CTRL6_C             0X15
#define LSM6DSM_CTRL7_G             0X16
#define LSM6DSM_CTRL8_XL            0X17

#define LSM6DSM_OUTX_L_G            0X22
#define LSM6DSM_OUTX_H_G            0X23
#define LSM6DSM_OUTY_L_G            0X24
#define LSM6DSM_OUTY_H_G            0X25
#define LSM6DSM_OUTZ_L_G            0X26
#define LSM6DSM_OUTZ_H_G            0X27

#define LSM6DSM_OUTX_L_XL           0X28
#define LSM6DSM_OUTX_H_XL           0X29
#define LSM6DSM_OUTY_L_XL           0X2A
#define LSM6DSM_OUTY_H_XL           0X2B
#define LSM6DSM_OUTZ_L_XL           0X2C
#define LSM6DSM_OUTZ_H_XL           0X2D

/**
   Structures
*/

//
typedef struct canTechMsg {
  //  char[10] sensorModuleMACAddress;

  float accX;
  float accY;
  float accZ;

  float gyroX;
  float gyroY;
  float gyroZ;

  float temperature;
};

/**
   Constants
*/
#define SERIAL_BAUD_RATE            115200
#define ESP32_WIFI_MODE             WIFI_STA

//const char* READER_WIFI_SSD         "CANnect_Reader_WiFi_0.1"   // SSID of reader WiFi
//const char* READER_WIFI_PASSWORD    "redboats"                  // Password of reader WiFi

/**
   Variables
*/
//uint8_t selfMACAddress[];
//uint8_t readerMACAddress[];
//esp_now_peer_info_t readerInfo;

void setup() {
  Serial.begin(SERIAL_BAUD_RATE);
  Serial.println("Wait for user to be ready");
  while (true) {

    if (Serial.available() > 0) {
      if (Serial.read() == 'G') {
        break;
      }
    }
  }

  imuSetup();
  wifiSetup();
  espNOWSetup();
}

void imuSetup(void) {
  Wire.begin(IMU_SDA, IMU_SCL);

  while (readRegister(LSM6DSM_WHO_AM_I_REG) != WHO_AM_I_REG_VALUE) {
    Serial.println("Unable to talk to IMU! Trying again!");
    delay(1000);
  }

  /**
     Taken from LSM library
  */
  //set the gyroscope control register to work at 104 Hz, 2000 dps and in bypass mode
  writeRegister(LSM6DSM_CTRL2_G, 0x4C);

  // Set the Accelerometer control register to work at 104 Hz, 4G,and in bypass mode and enable ODR/4
  // low pass filter(check figure 9 on LSM6DSM's datasheet)
  writeRegister(LSM6DSM_CTRL1_XL, 0x4A); // I think this is correct??

  // set gyroscope power mode to high performance and bandwidth to 16 MHz
  writeRegister(LSM6DSM_CTRL7_G, 0x00);

  // Set the ODR config register to ODR/4
  writeRegister(LSM6DSM_CTRL8_XL, 0xA4); // I think this is correct??

  Serial.println("IMU ready");
}

void wifiSetup(void) {
  WiFi.mode(ESP32_WIFI_MODE);
  Serial.println(WiFi.macAddress());
}

void espNOWSetup(void) {
  if (esp_now_init() != ESP_OK) {
    Serial.println("Error initializing ESP-NOW");
    return;
  }
}

int writeRegister(uint8_t address, uint8_t value)
{
  Wire.beginTransmission(LSM6DSM_ADDRESS);
  Wire.write(address);
  Wire.write(value);
  if (Wire.endTransmission() != 0) {
    return 0;
  }

  return 1;
}

int readRegister(uint8_t address) {
  uint8_t value;

  if (readRegisters(address, &value, sizeof(value)) != 1) {
    return -1;
  }

  return value;
}

int readRegisters(uint8_t address, uint8_t* data, size_t length) {
  Wire.beginTransmission(LSM6DSM_ADDRESS);
  Wire.write(address);

  if (Wire.endTransmission(false) != 0) {
    return -1;
  }

  if (Wire.requestFrom(LSM6DSM_ADDRESS, length) != length) {
    return 0;
  }

  for (size_t i = 0; i < length; i++) {
    *data++ = Wire.read();
  }

  return 1;
}

int gyroscopeAvailable() {
  if (readRegister(LSM6DSM_STATUS_REG) & 0x02) {
    return 1;
  }

  return 0;
}

int accelerationAvailable() {
  if (readRegister(LSM6DSM_STATUS_REG) & 0x01) {
    return 1;
  }

  return 0;
}

int readGyroscope(float& x, float& y, float& z) {
  int16_t data[3];

  if (!readRegisters(LSM6DSM_OUTX_L_G, (uint8_t*)data, sizeof(data))) {
    x = NAN;
    y = NAN;
    z = NAN;

    return 0;
  }

  x = data[0] * 2000.0 / 32768.0;
  y = data[1] * 2000.0 / 32768.0;
  z = data[2] * 2000.0 / 32768.0;

  return 1;
}

int readAcceleration(float& x, float& y, float& z) {

  int16_t data[3];

  if (!readRegisters(LSM6DSM_OUTX_L_XL, (uint8_t*)data, sizeof(data))) {
    x = NAN;
    y = NAN;
    z = NAN;

    return 0;
  }

  x = data[0] * 4.0 / 32768.0;
  y = data[1] * 4.0 / 32768.0;
  z = data[2] * 4.0 / 32768.0;

  return 1;
}

char* convert_int16_to_str(int i) { // converts int16 to string. Moreover, resulting strings will have the same length in the debug monitor.
  char tmp_str[7];
  sprintf(tmp_str, "%6d", i);
  return tmp_str;
}

//// Callback when data is sent
//void OnDataSent(const uint8_t *mac_addr, esp_now_send_status_t status) {
//  Serial.print("\r\nLast Packet Send Status:\t");
//  Serial.println(status == ESP_NOW_SEND_SUCCESS ? "Delivery Success" : "Delivery Fail");
//  if (status == 0) {
//    success = "Delivery Success :)";
//  }
//  else {
//    success = "Delivery Fail :(";
//  }
//}

//void connectToReader() {
//  WiFi.begin(READER_WIFI_SSD, READER_WIFI_PASSWORD);
//
//  while (WiFi.status() != WL_CONNECTED) {
//    delay(500);
//    Serial.println("Attempting to connect to WiFi");
//  }
//}

/**
   Register and add reader
*/
//void espNOWAddReader(uint8_t broadcastAddress) {
//  if (esp_now_is_peer_exist(broadcastAddress)) {
//    memcpy(readerInfo.peer_addr, broadcastAddress, 6);
//    readerInfo.channel = 0;
//    readerInfo.encrypt = false;
//
//    // Add peer
//    if (esp_now_add_peer(&readerInfo) != ESP_OK) {
//      Serial.println("Failed to add peer");
//      return;
//    }
//  }
//
//  else {
//    Serial.println("Unexpected behaviour!");
//    return;
//  }
//}

/**
   Remove reader
*/
//void espNOWRemoveReader(void) {
//  if (esp_now_del_peer(&readerInfo) != ESP_OK) {
//    Serial.println("Failed to delete peer gracefully");
//    return;
//  }
//}

void loop() {
  float x, y, z;

  if (gyroscopeAvailable()) {
    readGyroscope(x, y, z);

    Serial.print("Gyroscope: ");
    Serial.print(x);
    Serial.print('\t');
    Serial.print(y);
    Serial.print('\t');
    Serial.println(z);
  }

  if (accelerationAvailable()) {
    readAcceleration(x, y, z);

    Serial.print("Acceleration: ");
    Serial.print(x);
    Serial.print('\t');
    Serial.print(y);
    Serial.print('\t');
    Serial.println(z);
  }

  delay(100);
}

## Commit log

2020-11-23 Created initial draft of ESP32 sensor module
    [battery.sch, connector.sch, connnector.sch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]
2020-11-23 Deleted a header pin. Started working on PCB
    [battery.sch, connnector.sch, esp32_chip.sch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]
2020-11-23 Created PCB design for ESP32 sensor for v0.0.1. Exported PDFs and gerber files
    [connnector.sch, esp32_chip.sch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]
2020-11-25 Added ESP32 datasheets
2020-11-25 Added power regulator and imu datasheets
2020-11-25 Updated schematic and PCB design to v0.0.2 for 2-layer pcb. Added more silkscreen text
    [connnector.sch, esp32_chip.sch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]
2020-11-25 Updated sensor module and PCB design to v0.0.3. Fixed design issues with USB. Updated via size to 0.6mm. Moved polarised capacitor towards inside the board
    [connnector.sch, esp32_chip.sch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]
2020-11-25 Fixed silkscreen to display properly. Moved header pin silkscreen to bottom
    [esp32_sensor-B_Cu.gbr, esp32_sensor-B_Mask.gbr, esp32_sensor-B_Paste.gbr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]
2020-11-25 Updated PCB to v0.0.3b. Fixed tracks and silkscreen.
    [esp32_sensor-B_Adhes.gbr, esp32_sensor-B_CrtYd.gbr, esp32_sensor-B_Cu.gbr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]
2020-12-02 Implemented ESP32 Arduino software that extracts the gyroscope and acceleration data
2020-12-03 Begun implementing ESPNOW and WiFi functionality. Updated BOM.ini
2021-04-01 Re-exported KiCAD PCB files for assembly house/manufacturing. Updated README.md. Included BOM list
    [esp32_sensor-B_Adhes.gbr, esp32_sensor-B_CrtYd.gbr, esp32_sensor-B_Cu.gbr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]
